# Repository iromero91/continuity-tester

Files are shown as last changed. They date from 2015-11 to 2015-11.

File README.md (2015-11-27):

# Low Power Continuity Tester

These are the hardware and software design files for my square inch
contest entry, the low power continuity tester.

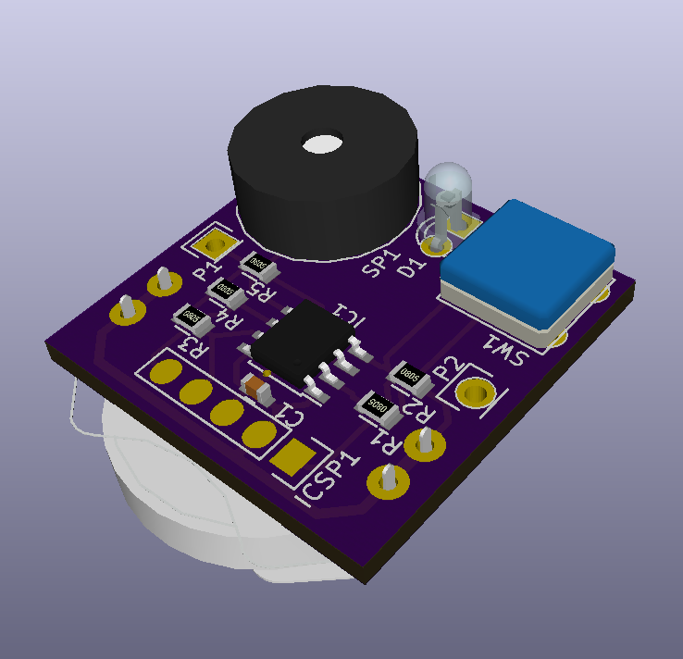
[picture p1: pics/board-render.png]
3D Rendering


## Goals

The design goals for this project are the following:

* **Small size**: maximum of 1 square inch PCB area.

* **Low power**: Should run for a decent amount on time on a single
  CR2032 cell.

* **Fully featured**: Have at least:

  * *Low voltage continuity test mode*: Compliance voltage < 0.5v, low
    current.

  * *Inverse continuity mode*: Beep if continuity is broken.

  * *Both modes with "latching" glitch capture*: start beeping
    immediately and keep beeping for at least a split second.

  * *Diode test mode*: Short beep on forward voltage within diode drop
    (0.1-0.7v), continuous beep on short circuit.

* **Simple to use**: no power switch, turn on by touching probes, mode
  switch with a single button.

* **Low cost!**

## Implementation

To achieve all those goals I decided to base my implementation around
a microcontroller, namely the PIC12LF1571, which is a stunningly cheap
and feature packed device. Digikey has it for
[50 cents a piece][PIC12LF1571-I/SN-ND] at quantity 10! that's barely
17 cents more than what you'd pay for a humble [555][LM555CMFS-ND]!
For your 50 cents you get quite a spread of peripherals: a fixed
voltage reference, a 10 bit adc, a 5 bit DAC(!), 3 16-bit PWMs (!!),
the standard 3 timers on top of that, analog comparator, 3.5k of flash
and 256 bytes of SRAM. Truly remarkable.

Another remarkable thing about this chip which makes it suitable to
achieve my goals is that it can be made to operate under very low
voltages (down to 1.8v) and using very little power. As low as a few
hundred nanowatts (that's less than a millionth of a watt) while
sleeping, allowing standby times measured in years.

### Electronics

The analog part of the circuit is extremely simplistic, just 3
resistors. The design is inspired on [elm-chan's][elms-tester] tester,
but with an aditional IO pin on the negative side of the resistor
divider. This extra pin provides aditional control for the diode test
feature and allows the tester to be turned on by touching probes.

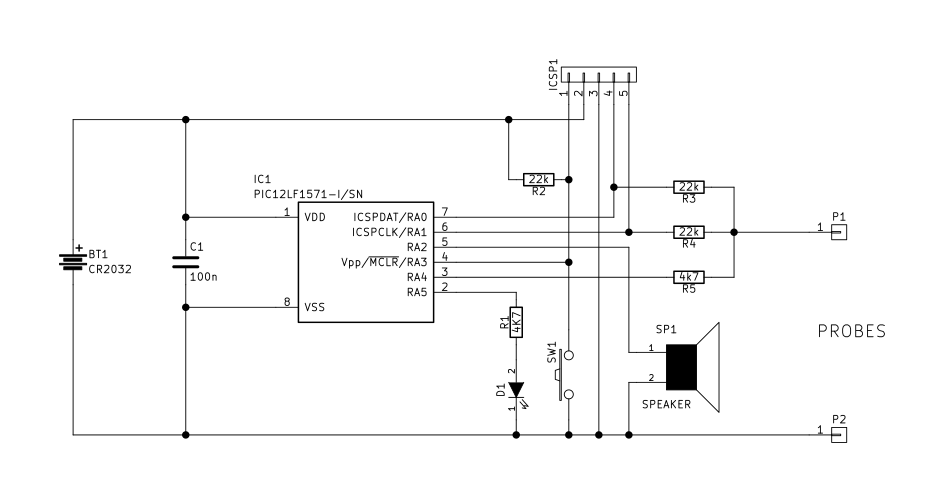
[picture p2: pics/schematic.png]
Schematic


The simplicity of the circuit is also it's Achiles Heel, it doesn't
provide any input protection at all, relying instead on the built in
protection diodes of the microcontroller. The reason why I didn't
include any input protection is because I couldn't find any protection
scheme that would afford enough protection without compromising power
consumption or precision. For example, using a simple 3.3v zener diode
on the input would leak an appreciable amount of current at 3V, so
much in fact that the diode itself would consume more power than the
pic does while asleep! *This circuit should never be used on circuits
under power, and certainly NOT anywhere near any mains/line power
cables!!!*

### Firmware

The firmware is written in C, using Microchip's MPLAB X and XC8
compiler in free mode. The code is configured as a simple state
machine:

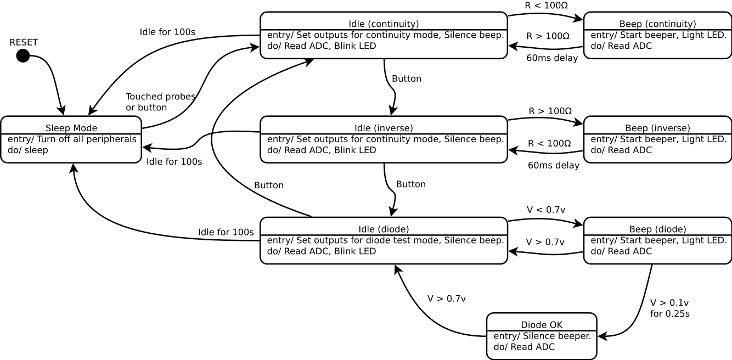
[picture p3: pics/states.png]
State diagram


The CPU runs at the slowest internal oscillator speed (31kHz) to save
power. On reset it jumps straight into sleep mode, where it lays
dormant until a button press is detected or the leads are touched
together. That is achieved by setting up an interrupt on pin change
right before going to sleep, the interrupt hardware still works
without a clock, which allows the processor to still be useful while
only using less than a microwatt of power.

Once it's woken up, the microcontroller enters a loop where it
continuously samples the ADC, detecting wether the resistance in
between the probes is low enough to signal continuity or not. The ADC
module and voltage references are turned on and off as necessary to
use as little power as possible. While in this mode I've measured an
average current consumption of around 150 to 200 microamps, which
would allow the tester to have over 800 hours of battery life.

Each idle state blinks the led to signal which mode the tester is in,
for continuity it's a single blink followed by a long pause, for
inverse continuity it's 2, and for diodes it's 3 fast blinks followed
by a long pause. The user can switch modes by pressing the button.

When the condition of continuity (or discontinuity) is detected, the
beeper is turned on, using one of the PWM channels to output a square
wave into the piezo buzzer. Once there is no more continuity (or
discontinuity), a count is started so that any "glitch" is stretched
to at least a split second, making it easier to hear sporadic
contacts.

The diode tester is slightly different, the beeper is started as soon
as the voltage in the tips is below 0.7V (a typical silicon diode
drop), and will stop a split second later if that voltage stays above
0.1V (just below what would drop on a shottky diode). If it's any
longer, the beeper will stay on indefinitely. This mode makes it easy
to test diodes for opens and shorts since a normal diode would produce
a short beep, a shorted diode would produce a continuous beep, and an
open one wouldn't beep at all.

## Bill of materials

* Main chip: U1, [Microchip PIC12LF1571][PIC12LF1571-I/SN-ND] ($0.50 @ qty 10)
* Buzzer: SP1, [Murata PKM13EPYH4000-A0][490-4698-ND] ($0.49 @ qty 10)
* Battery Holder: BT1, [Linx BAT-HLD-001-THM][BAT-HLD-001-THM-ND] ($0.28 @ qty 10)
* Button: SW1, [TE Connectivity 1825910-7][450-1804-ND] ($0.06 @ qty 10)
* Decoupling cap: C1, 100nF, 0603, ceramic. (~$0.02)
* Resistors: R1, R5, 4k7; R2, R3, R4, 22k; 0805 resistors (~$0.05)
* PCB: OSHPark 3 1x1 inch boards for $5 ($1.66 ea)
 
**Total bom cost for a prototype run**: $3.06 each! (more than half of it is the prototype PCB)

## License

Copyright 2015 Jose I. Romero.

The schematic, PCB and firmware are free software, released under the
GNU GPL as published by the Free Software Foundation, version 3. See
LICENSE.txt for more details.

[PIC12LF1571-I/SN-ND]: http://www.digikey.com/product-detail/en/PIC12LF1571-I%2FSN/PIC12LF1571-I%2FSN-ND/4739318
[LM555CMFS-ND]: http://www.digikey.com/product-detail/en/LM555CM/LM555CMFS-ND/1051271
[elms-tester]: http://elm-chan.org/works/cch/report_e.html
[490-4698-ND]: http://www.digikey.com/product-detail/en/PKM13EPYH4000-A0/490-4698-ND/1219329
[BAT-HLD-001-THM-ND]: http://www.digikey.com/product-detail/en/BAT-HLD-001-THM/BAT-HLD-001-THM-ND/3044009

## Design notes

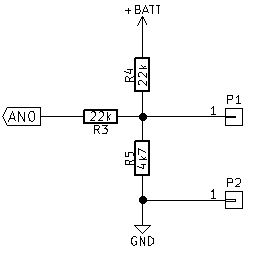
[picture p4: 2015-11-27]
pics/cont_ckt.png

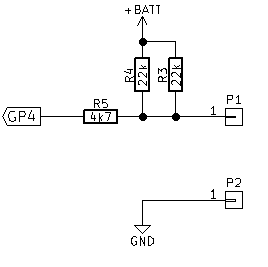
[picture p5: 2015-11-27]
pics/stby_ckt.png

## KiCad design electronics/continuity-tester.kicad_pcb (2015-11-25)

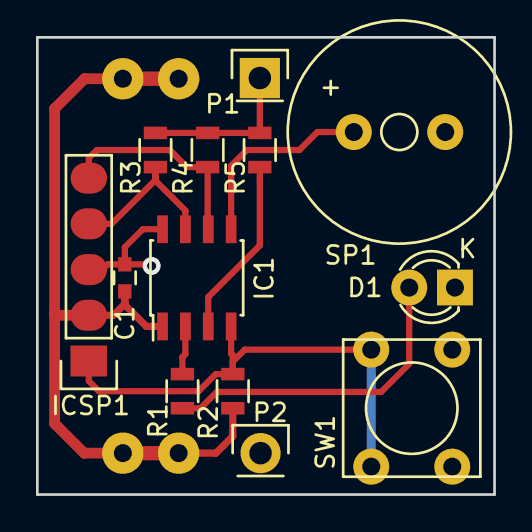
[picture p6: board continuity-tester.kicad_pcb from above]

Board: 2 copper layers, 25.4 x 25.4 mm, 14 parts (1 on the bottom side), 10 nets.

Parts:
BT1: CR2032; BAT-HLD-001-THM-OTL
C1: 100n; C_0603
D1: LED; LED-3MM
IC1: PIC12LF1571-I/SN; SOIC-8_3.9x4.9mm_Pitch1.27mm
ICSP1: CONN_01X05; Pin_Header_Straight_1x05
P1, P2: CONN_01X01; Pin_Header_Straight_1x01
R1: 4K7; R_0805
R2, R3, R4: 22k; R_0805
R5: 4k7; R_0805
SP1: SPEAKER; Buzzer_12x9.5RM7.6
SW1: SW_PUSH; SW_PUSH_SMALL

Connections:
unnamed: BT1.1, C1.1, IC1.1, ICSP1.2, R2.2
unnamed: BT1.2, C1.2, D1.1, IC1.8, ICSP1.3, P2.1, SP1.2, SW1.1
unnamed: D1.2, R1.1
unnamed: IC1.2, R1.2
unnamed: IC1.3, R5.2
unnamed: IC1.4, ICSP1.1, R2.1, SW1.2
unnamed: IC1.5, SP1.1
unnamed: IC1.6, ICSP1.5, R4.2
unnamed: IC1.7, ICSP1.4, R3.2
unnamed: P1.1, R3.1, R4.1, R5.1

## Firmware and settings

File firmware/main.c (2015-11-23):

/*
 * Copyright 2015 José I. Romero
 *
 * This file is part of "Low Power Continuity Tester".
 *
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
 * Created on November 13, 2015, 5:49 PM
 */

#include <xc.h>
#include <stdint.h>

// CONFIG1
#pragma config FOSC = INTOSC    //  (INTOSC oscillator; I/O function on CLKIN pin)
#pragma config WDTE = OFF       // Watchdog Timer Enable (WDT disabled)
#pragma config PWRTE = OFF      // Power-up Timer Enable (PWRT disabled)
#pragma config MCLRE = OFF      // MCLR Pin Function Select (MCLR/VPP pin function is digital input)
#pragma config CP = OFF         // Flash Program Memory Code Protection (Program memory code protection is disabled)
#pragma config BOREN = OFF      // Brown-out Reset Enable (Brown-out Reset disabled)
#pragma config CLKOUTEN = OFF   // Clock Out Enable (CLKOUT function is disabled. I/O or oscillator function on the CLKOUT pin)

// CONFIG2
#pragma config WRT = OFF        // Flash Memory Self-Write Protection (Write protection off)
#pragma config PLLEN = OFF      // PLL Enable (4x PLL disabled)
#pragma config STVREN = OFF     // Stack Overflow/Underflow Reset Enable (Stack Overflow or Underflow will not cause a Reset)
#pragma config BORV = LO        // Brown-out Reset Voltage Selection (Brown-out Reset Voltage (Vbor), low trip point selected.)
#pragma config LPBOREN = OFF    // Low Power Brown-out Reset enable bit (LPBOR is disabled)
#pragma config LVP = OFF        // Low-Voltage Programming Enable (High-voltage on MCLR/VPP must be used for programming)

#define LFINTOSC_FREQ 31000 /* 31kHz LFINTOSC */

#define VCC 3.0
#define RP 22000.0
#define RN 4700.0
#define ADC_VREF 1.024
#define ADC_COUNTS 1024
#define ADC_VOLT(x) (uint16_t)(ADC_COUNTS * (x) / ADC_VREF)
#define ADC_OHM(x) ADC_VOLT(1/(1/RN + 1/(x)) * VCC / (RP + 1/(1/RN + 1/(x))))

// Time before falling into sleep mode
#define IDLE_TIME 5000 /* ~100s */

// Continuity test constants
#define OPEN_TRESHOLD ADC_OHM(150.0)
#define SHORT_TRESHOLD ADC_OHM(100.0)
#define LATCH_TIME 4     /* ~60ms */

// Diode test constants
#define DIODE_TRESHOLD_MAX ADC_VOLT(0.6)
#define DIODE_TRESHOLD_MIN ADC_VOLT(0.07)
#define DIODE_BEEP_TIME 7     /* ~0.12s */

#define BEEP_FREQ 1333.33
#define BEEP_PERIOD (uint16_t)(LFINTOSC_FREQ / BEEP_FREQ)

// Tester states
typedef enum state_t {
    ST_SLEEP,
    ST_CONTINUITY_IDLE,
    ST_CONTINUITY_BEEP,
    ST_INVERSE_IDLE,
    ST_INVERSE_BEEP,
    ST_DIODE_IDLE,
    ST_DIODE_BEEP,
    ST_DIODE_OK
} state_t;

static state_t State;  // Current state

void beep() {
    PWM3CON    = 0b11000000; // Enable PWM
    PWM3CLKCON = 0b00000010; // LFINTOSC clock source, no prescaler
    PWM3PH = 0;
    PWM3PR = BEEP_PERIOD; // Set oscillator period
    PWM3DC = BEEP_PERIOD / 2; // 50% duty cycle
    PWM3LDCONbits.PWM3LD = 1; // Load registers!
}

void unbeep() {
    PWM3CON = 0; // PWM 3 OFF
    PWM3CLKCON = 0;
}

void adc_init() {
    ANSELA = 0b00000001; // Use AN0
    ADCON1bits.ADCS = 0b111; // Use FRC clock
    ADCON1bits.ADFM = 1; // Right justified format
    ADCON1bits.ADPREF = 0b00; // Reference tied to VCC
}


uint16_t adc_read () {
    // Turn on voltage reference
    FVRCON = 0b10000001; // 1x gain for ADC
    while (!FVRCONbits.FVRRDY) NOP(); // Wait until FVR is ready
    ADCON1bits.ADPREF = 0b11; // Set ADC reference to FVR
    // Acquire ADC sample
    ADCON0bits.CHS = 0;  // Channel 0 (GP0)
    ADCON0bits.ADON = 1; // Turn on ADC
    ADCON0bits.GO = 1; // Start conversion
    while (ADCON0bits.GO_nDONE) NOP(); // Wait for result
    ADCON0bits.ADON = 0; // Turn off ADC
    FVRCON = 0; // Turn off FVR
    return (ADRESH<<8) + ADRESL;
}

void blink_mode(uint8_t t, uint8_t mode) {
    if (t < mode) {
        LATAbits.LATA5 = ((t & 8) && (t & 4))? 1 : 0;
    } else {
        LATAbits.LATA5 = 0;
    }
}

uint8_t check_button() {
    static int8_t Debounce = 0;
    if (PORTAbits.RA3 == 0) {
        if (Debounce >= 0) Debounce++;
    } else {
        Debounce = 0;
    }
    if (Debounce > LATCH_TIME) {
        Debounce = -1; // Block the button until it's released.
        return 1;
    }
    return 0;
}

/*
 * Sleep State
 */
void state_sleep() {
    /*** Enter State ***/
    // Configure IO
    TRISA = 0b00011000; // Only enable button (RA3) and probe (RA4) inputs
    LATA  = 0b00000011; // Pull up RA0 (27K) and RA1 (10k)
    IOCAN = 0b00011000; // Enable wake up on negative edge for probe and button
    WPUA = 0; // No weak pullups
    OPTION_REGbits.nWPUEN = 1;
    ODCONA = 0; // All IO is push-pull
    SLRCONA = 0; // Slew rate at maximum
    // Configure ADC
    ANSELA  = 0; // All pins digital
    ADCON0 = 0; // Turn off ADC
    // Configure Comparator Module
    CM1CON0 = 0; // Comparator off
    // Configure PWM
    PWM3CON = 0; // PWM3 (buzzer) off
    CWG1CON0 = 0; // CWG off.
    // Configure interrupts
    INTCONbits.IOCIE = 1; // Enable wake up on pin change.
    INTCONbits.IOCIF = 0; // Clear flag.
    /*** In State ***/
    do {
        SLEEP(); // Sleep until either the probe or button wakes us up.
        NOP();
        INTCONbits.IOCIF = 0; // Clear flag
        IOCAF = 0; // And flags
    } while (PORTAbits.RA3 && PORTAbits.RA4);
    /*** Exit State ***/
    INTCONbits.IOCIE = 0; // Disable GPIO interrupts
    IOCAN = 0;
    State = ST_CONTINUITY_IDLE;
    return;
}

///// Continuity Mode States /////

void state_continuity_idle() {
    state_t next = ST_SLEEP;
    uint16_t time = 0;

    /*** Enter State ***/
    unbeep(); // Silence BEEP
    // Configure IO
    TRISA = 0b00001001; // Set up GP0 (probe) and GP3 (button) as inputs
    LATA  = 0b00000010; // Activate bias current for cont. test (22k series R)
    adc_init(); // Configure ADC

    /*** In State ***/
    while(time < IDLE_TIME) {  // Go back to sleep if idling too long
        if (State == ST_CONTINUITY_IDLE) {
            blink_mode(time&127, 1*16);
            if (check_button()){
                next = ST_INVERSE_IDLE; // Cycle to next mode
                break;
            } else if (adc_read() < SHORT_TRESHOLD) {
                next = ST_CONTINUITY_BEEP; // Jump immediately (glitch capture)
                break;
            }
        } else { // ST_INVERSE_IDLE
            blink_mode(time&127, 2*16);
            if (check_button()){
                next = ST_DIODE_IDLE; // Cycle to next mode
                break;
            } else if (adc_read() > OPEN_TRESHOLD) {
                next = ST_INVERSE_BEEP; // Jump immediately (glitch capture)
                break;
            }
        }
        time++;
    }
    /*** Exit State ***/
    State = next;
    return;
}

void state_continuity_beep() {
    state_t next = ST_CONTINUITY_IDLE;
    uint8_t samples = 0;

    /*** Enter State ***/
    beep(); // Start beeper
    LATAbits.LATA5 = 1; // Turn on LED

    /*** In State ***/
    while(samples < LATCH_TIME) {
        if (State == ST_CONTINUITY_BEEP) {
            if (check_button()) {
                next = ST_INVERSE_IDLE; // Cycle to next mode
                break;
            }else if (adc_read() > OPEN_TRESHOLD) {
                samples++;
            } else {
                samples = 0;
            }
        } else { // ST_INVERSE_BEEP
            if (check_button()) {
                next = ST_DIODE_IDLE; // Cycle to next mode
                break;
            }else if (adc_read() < SHORT_TRESHOLD) {
                samples++;
                next = ST_INVERSE_IDLE;
            } else {
                samples = 0;
            }
        }
    }

    /*** Exit State ***/
    State = next;
    return;
}

///// Diode Mode States /////

void state_test_ADC() {
    state_t next = ST_SLEEP;
    uint16_t voltage;
    uint8_t i;

    /*** Enter State ***/
    unbeep(); // Silence BEEP
    // Configure IO
    TRISA = 0b00001001; // Set up GP0 (probe) and GP3 (button) as inputs
    LATA  = 0b00010000; // Activate bias current for diode test (4k7 series R)
    adc_init(); // Configure ADC

    /*** In State ***/
    while(1) {
        voltage = adc_read();
        LATAbits.LATA5 = 0;
        LATAbits.LATA5 = 1;
        NOP();NOP();NOP();NOP();NOP();NOP();
        LATAbits.LATA5 = 0;
        for (i=0;i<16;i++) {
            LATAbits.LATA5 = 0;
            LATAbits.LATA5 = 1;
            LATAbits.LATA5 = 0;
            LATAbits.LATA5 = voltage & 1;
            voltage = voltage / 2;
        }
        LATAbits.LATA5 = 0;

        if (check_button()) {
            next = ST_CONTINUITY_IDLE;  // Cycle to next mode
            break;
        }
    }

    /*** Exit State ***/
    State = next;
    return;
}

void state_diode_idle() {
    state_t next = ST_SLEEP;
    uint16_t time = 0;

    /*** Enter State ***/
    unbeep(); // Silence BEEP
    // Configure IO
    TRISA = 0b00001001; // Set up GP0 (probe) and GP3 (button) as inputs
    LATA = 0b00010000; // Activate bias current for diode test (4k7 series R)
    adc_init(); // Configure ADC

    /*** In State ***/
    while(time < IDLE_TIME) { // Go back to sleep if idling too long
        blink_mode(time&127, 3*16);
        if (check_button()) {
            next = ST_CONTINUITY_IDLE;  // Cycle to next mode
            break;
        } else if (adc_read() < DIODE_TRESHOLD_MAX) {
            next = ST_DIODE_BEEP;
            break;
        }
        time++;
    }

    /*** Exit State ***/
    State = next;
    return;
}

void state_diode_beep() {
    state_t next = ST_DIODE_OK;
    uint8_t samples = 0;
    uint16_t voltage;

    /*** Enter State ***/
    beep(); // Start beeper
    LATAbits.LATA5 = 1; // Turn on LED

    /*** In State ***/
    while(samples < DIODE_BEEP_TIME) {
        voltage = adc_read();
        if (check_button()) {
            next = ST_CONTINUITY_IDLE; // Cycle to next mode
            break;
        }else if (voltage > DIODE_TRESHOLD_MAX) {
            next = ST_DIODE_IDLE; // Probes open, abort
            break;
        } else if (voltage > DIODE_TRESHOLD_MIN){
            samples++;
        } else {
            samples = 0;
        }
    }

    /*** Exit State ***/
    State = next;
    return;
}

void state_diode_ok() {
    state_t next  = ST_DIODE_IDLE;
    /*** Enter State ***/
    unbeep(); // Silence beeper

    /*** In State ***/
    while (adc_read() <= DIODE_TRESHOLD_MAX) {
        if (check_button()){
            next = ST_CONTINUITY_IDLE;
            break;
        };
    }

    /*** Exit State ***/
    State = next;
    return;
}

int main () {
    OSCCON = 0; // 31KHz Internal Oscillator
    State = ST_SLEEP;
    for (uint8_t i=250; i--; i > 0) NOP();
    for (;;) {
        switch (State) {
        case ST_SLEEP:           state_sleep();           break;

        case ST_INVERSE_IDLE: // Fall through
        case ST_CONTINUITY_IDLE: state_continuity_idle(); break;
        case ST_INVERSE_BEEP: // Fall through
        case ST_CONTINUITY_BEEP: state_continuity_beep(); break;

        case ST_DIODE_IDLE:      state_diode_idle();      break;
        case ST_DIODE_BEEP:      state_diode_beep();      break;
        case ST_DIODE_OK:        state_diode_ok();        break;

        default:
            state_sleep();
        }
    }
}

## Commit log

2015-11-19 Initial revision
    [continuity-tester.sch]
2015-11-20 Timing analysis and optimization, sampling at ~50Hz
2015-11-21 Switched to PICkit3 for development
2015-11-21 Added battery holders library
2015-11-22 First revision of the PCB
    [continuity-tester.kicad_pcb, continuity-tester.sch]
2015-11-23 Improved ADC defines and use of fixed voltage reference.
    [main.c]
2015-11-23 Fix error in .gitignore, was not ignoring PCB backup files
2015-11-25 New PCB revision, sent to fab.
    [continuity-tester.kicad_pcb, continuity-tester.sch]

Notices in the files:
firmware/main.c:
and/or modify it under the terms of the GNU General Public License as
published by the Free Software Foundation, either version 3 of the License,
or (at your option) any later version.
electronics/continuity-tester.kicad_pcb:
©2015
